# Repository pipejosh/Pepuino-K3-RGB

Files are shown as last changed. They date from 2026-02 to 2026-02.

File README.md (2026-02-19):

# Pepuino K3 RGB 

Introducing the Pepuino K3 RGB, this is a custom macro pad made from scratch, currently designed to fit any rythm game like osu or geometry dash. The Pepuino K3 has 3 programable switches per light RGB lightning and a rotary encoder.

I made this project because I felt like it was time to jump from keyboard to a more small macro pad. I was orignally gonna buy one, but what a better opportunity to learn how to make one myself.

## Mode

In this current set up I have 2 layers, the Osu mode (ESC, z , x) and the Geometry Dash mode (Space , z , x) you can difference them by the led profile, the purple for Osu and the rainbow for Geometry Dash 

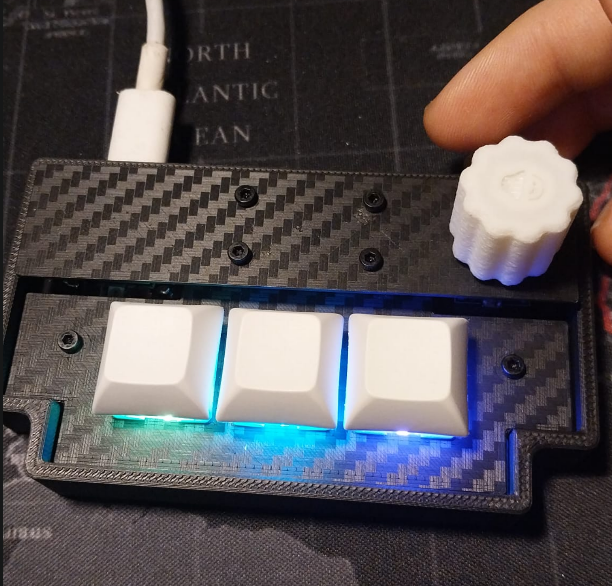
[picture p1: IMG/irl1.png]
geometryDashMode
 
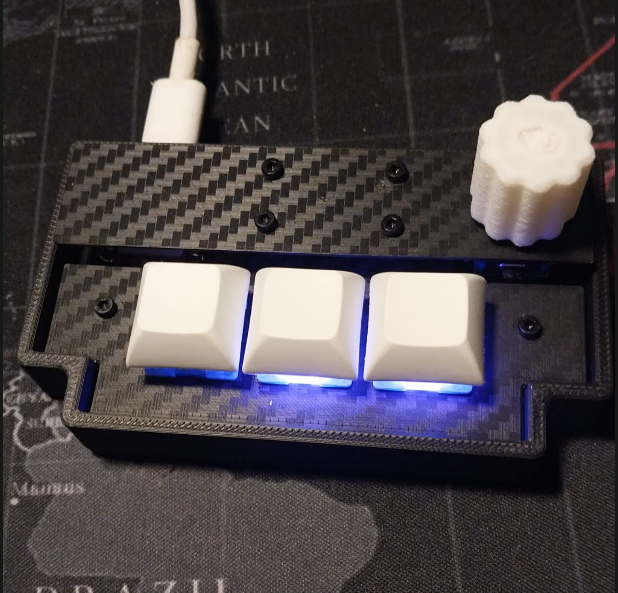
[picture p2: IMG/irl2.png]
osuMode
 

# Technical stuff

### SCHEMATIC DIAGRAM
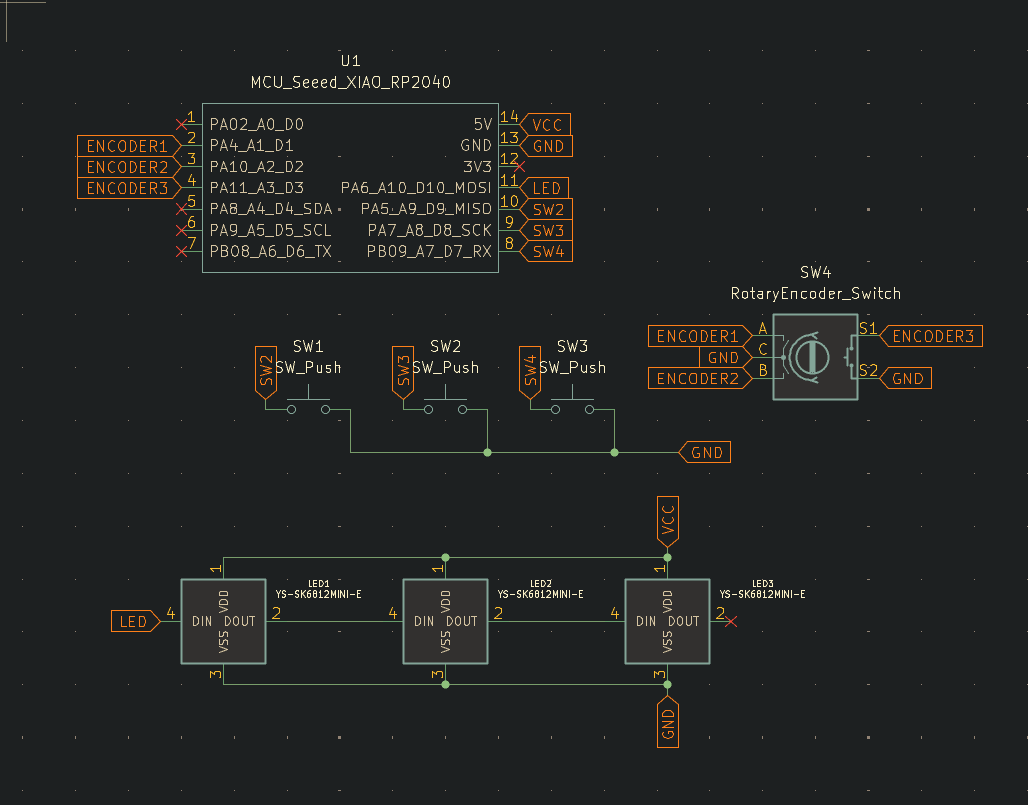
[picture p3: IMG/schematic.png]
shcematic
 

### PCB 
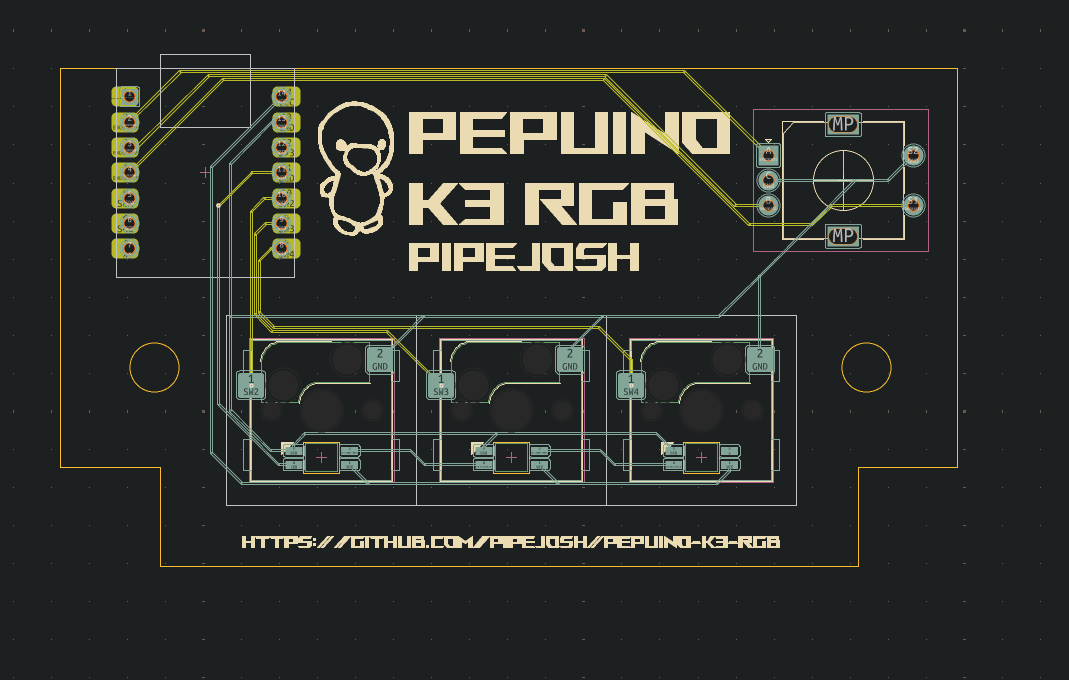
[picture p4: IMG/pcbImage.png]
pcb
 

### CASE RENDER
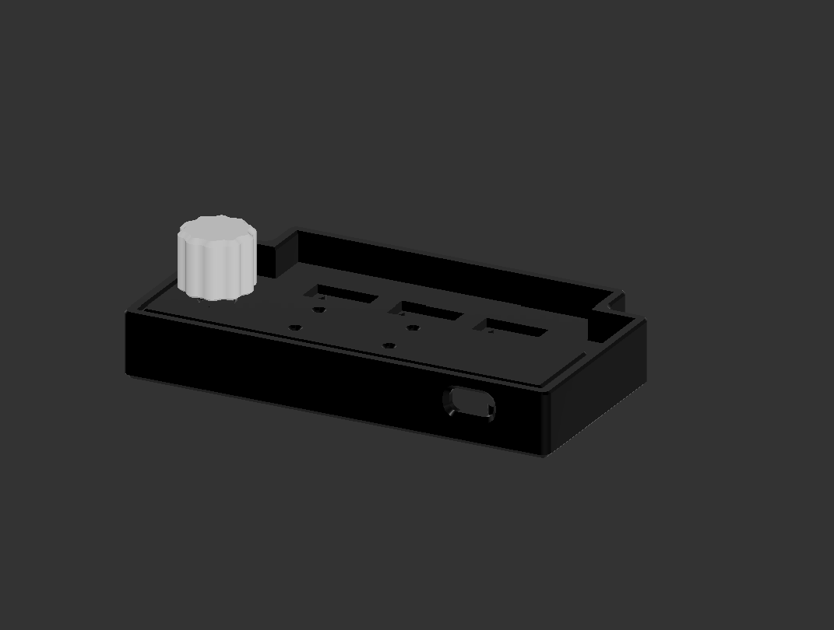
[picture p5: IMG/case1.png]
caseRender1
 
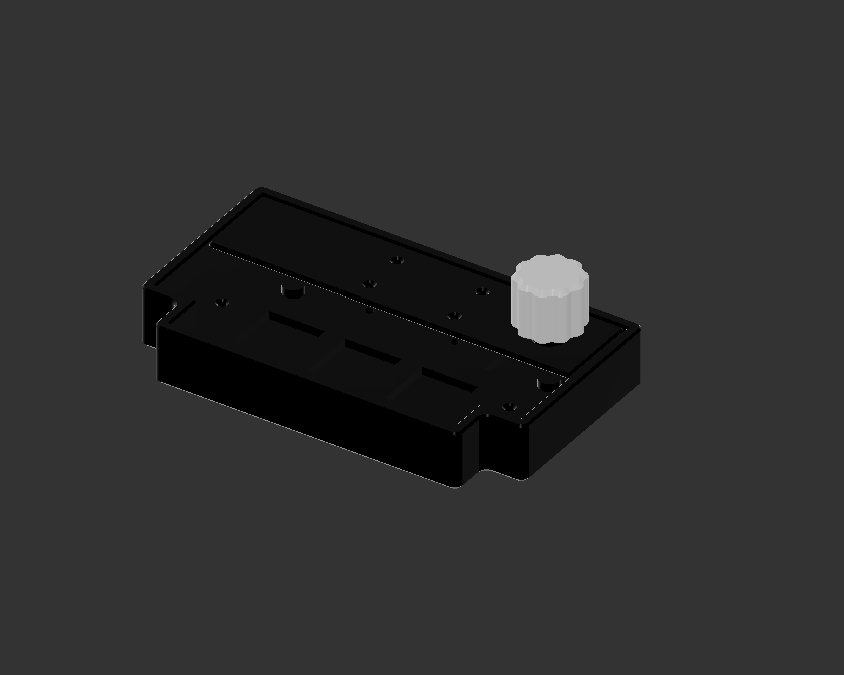
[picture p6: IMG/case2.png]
caseRender2
 

### BOM
####  Components

| Item | Description | Qty | Unit Price | Total Price |
|---|---|-----|---|---|
| xiao rp2040 | — | 1 | 4,54 | 4,54 |
| blank keycaps  | white | 20  | 0,19 | 3,77 |
| switches | mechanical switches| 10  | 0,39 | 3,9 |
| rotary encoder | — | 1 | 1,85 | 1,85 |
| M2 standoff | M2 standoff 5mm | 50  | 0,05 | 2,47 |
| M2 screw | 5mm screw | 50  | 0,03 | 1,65 |

#### Taxes

| Item  | Description | Total Price |
|---|---|---|
| taxes | aliexpress tax | 4,28 |

#### Components Subtotal

| Category | Total |
|---|---|
| Components | 22,46  |

---

#### PCB

| Item | Description | Qty |
|---|---|-----|
| JLCPCB | Pepuino Pad PCB | 1 |
| JLCPCB Shipping | Shipping for PCB + taxes  | 3 |

---

#### Grand Total

| TOTAL |
|-------|
| 26,46 |

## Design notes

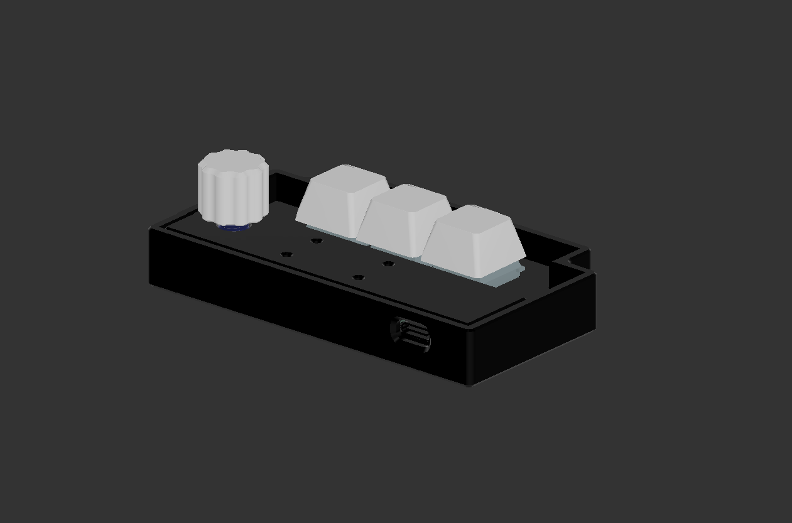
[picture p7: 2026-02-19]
IMG/render1.png

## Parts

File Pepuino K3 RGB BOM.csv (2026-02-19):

KIT Items | Description | Quantity | Unit Price | Total Price | URL
xiao rp2040 |  | 1 | 4,54 | 4,54 | https://www.aliexpress.com/item/1005006987582110.html
blank keycaps | white | 20 | 0,19 | 3,77 | https://www.aliexpress.com/item/1005006116865547.html?spm=a2g0o.detail.0.0.5325TAR5TAR5dv&mp=1
switches | mechanical switches | 10 | 0,39 | 3,9 | https://www.aliexpress.com/item/1005006425450443.html
rotary encoder |  | 1 | 1,85 | 1,85 | https://www.aliexpress.com/item/1005007644083514.html
M2 standoff | M2 standoff 5mm | 50 | 0,05 | 2,47 | https://www.aliexpress.com/item/1005008504707668.html?spm=a2g0o.detail.0.0.5fe4VqYfVqYfAJ&mp=1
M2 screw | 5mm screw | 50 | 0,03 | 1,65 | https://www.aliexpress.com/item/1005005070119421.html
taxes | aliexpress tax |  |  | 4,28
 |  |  | Components | 22,46
CASE Items | Description
JLCPCB | Pepuino Pad PCB | 1
JLCPCB Shipping | Shipping for PCB + taxes | 3
TOTAL | 26,46

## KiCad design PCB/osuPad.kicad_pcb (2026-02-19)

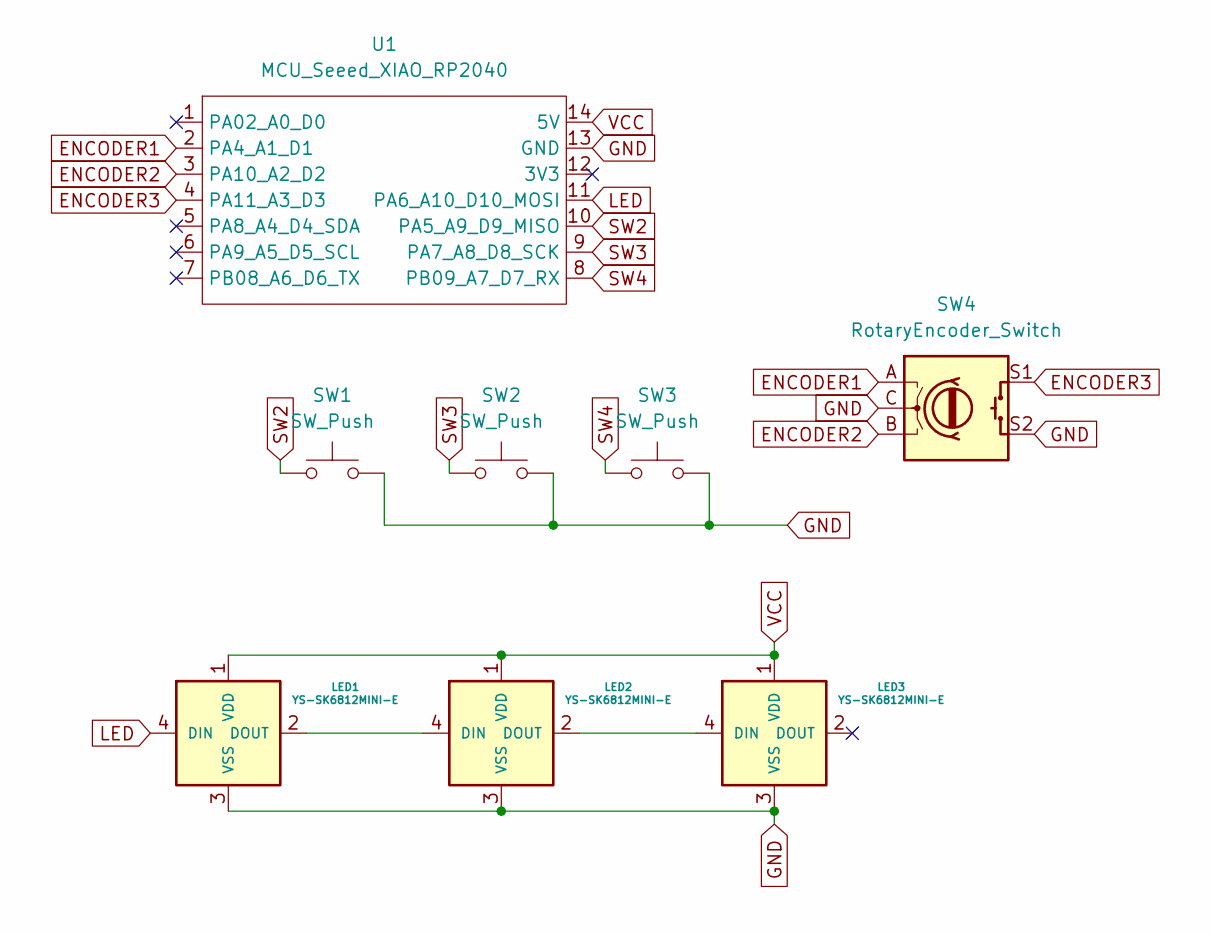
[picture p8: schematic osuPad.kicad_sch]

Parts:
LED1, LED2, LED3: YS-SK6812MINI-E
SW1, SW2, SW3: SW_Push; Hotswap_MX_1.00u
SW4: RotaryEncoder_Switch; RotaryEncoder_Alps_EC11E-Switch_Vertical_H20mm
U1: MCU_Seeed_XIAO_RP2040; Seeed_XIAO_RP2040

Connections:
3V3: U1.12 (3V3)
ENCODER1: SW4.A, U1.2 (PA4_A1_D1)
ENCODER2: SW4.B, U1.3 (PA10_A2_D2)
ENCODER3: SW4.S1, U1.4 (PA11_A3_D3)
GND: LED1.3 (VSS), LED2.3 (VSS), LED3.3 (VSS), SW1.2, SW2.2, SW3.2, SW4.C, SW4.S2, U1.13 (GND)
LED: LED1.4 (DIN), U1.11 (PA6_A10_D10_MOSI)
unnamed: LED1.2 (DOUT), LED2.4 (DIN)
unnamed: LED2.2 (DOUT), LED3.4 (DIN)
SCL: U1.6 (PA9_A5_D5_SCL)
SDA: U1.5 (PA8_A4_D4_SDA)
SW2: SW1.1, U1.10 (PA5_A9_D9_MISO)
SW3: SW2.1, U1.9 (PA7_A8_D8_SCK)
SW4: SW3.1, U1.8 (PB09_A7_D7_RX)
VCC: LED1.1 (VDD), LED2.1 (VDD), LED3.1 (VDD), U1.14 (5V)

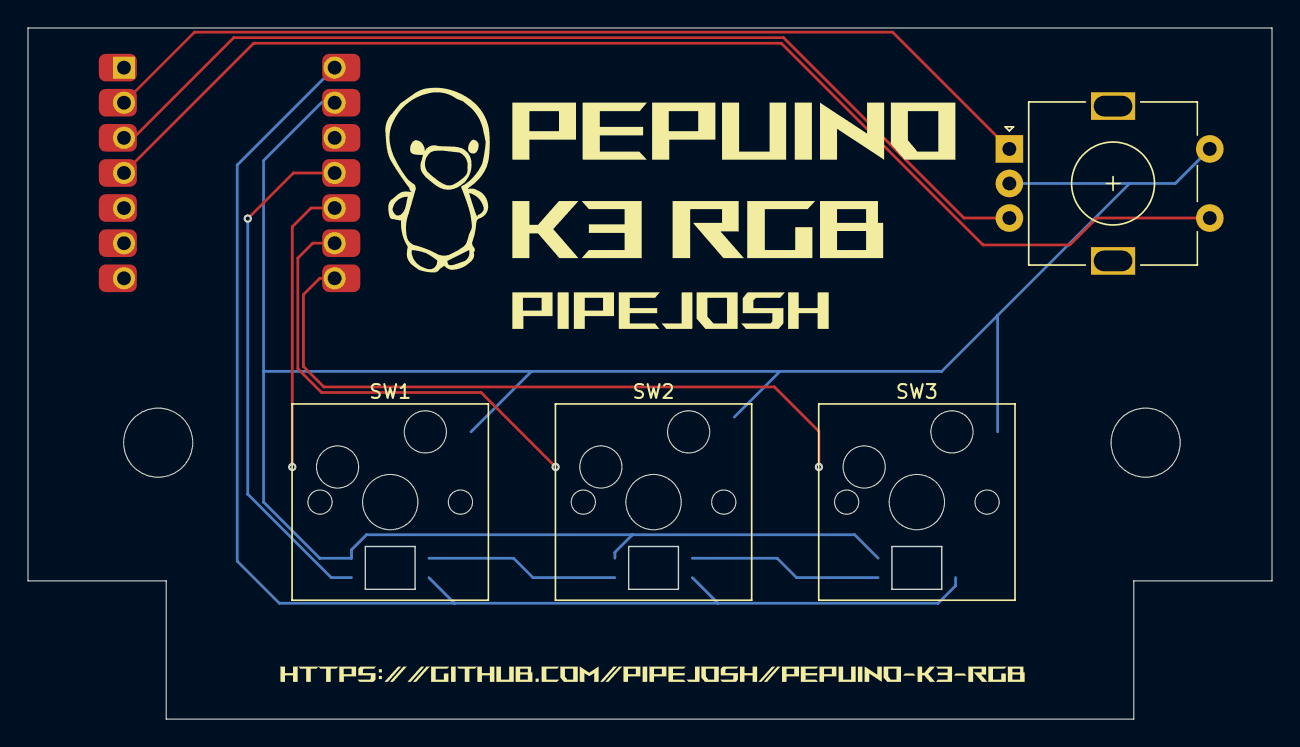
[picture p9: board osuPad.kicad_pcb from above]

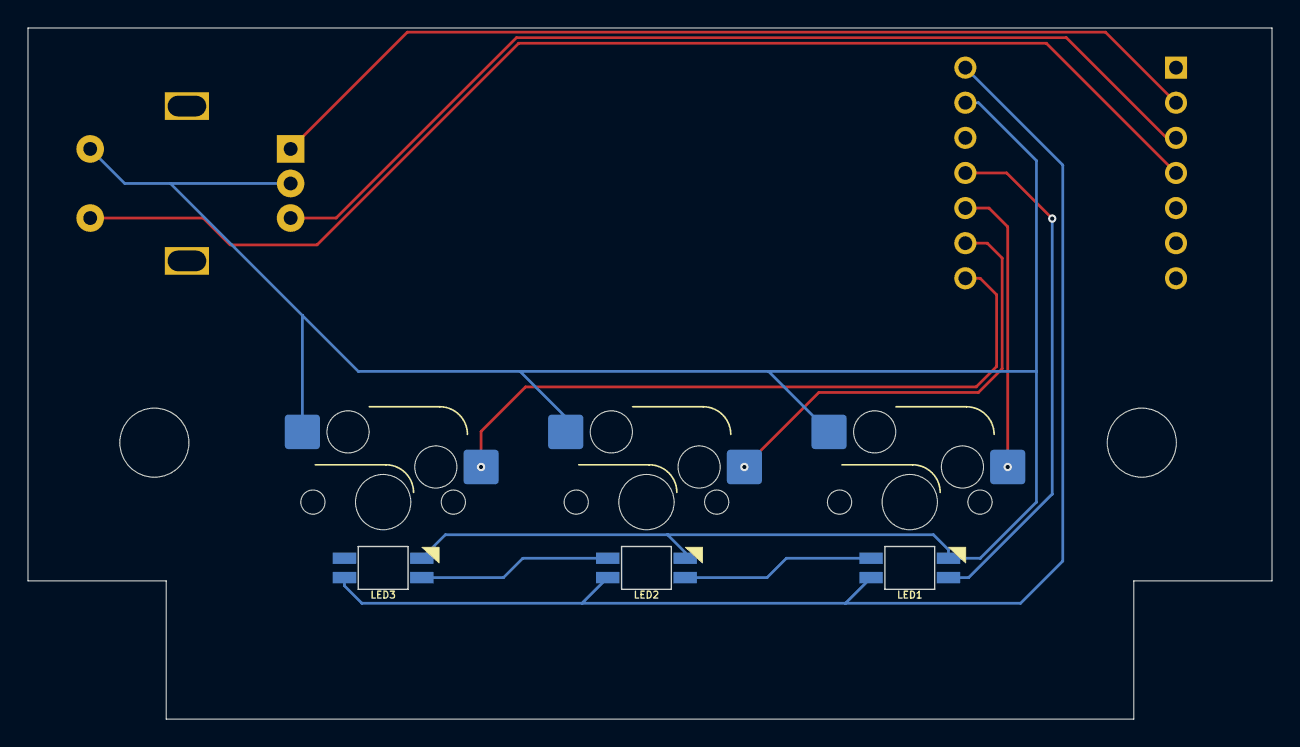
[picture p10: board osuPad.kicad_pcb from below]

Board: 2 copper layers, 90.0 x 50.0 mm, 8 parts (3 on the bottom side), 11 nets.

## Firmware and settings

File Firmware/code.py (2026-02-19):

import board
import time
import usb_hid
import neopixel
import rotaryio

from digitalio import DigitalInOut, Direction, Pull
from adafruit_hid.keyboard import Keyboard
from adafruit_hid.keycode import Keycode
from adafruit_hid.consumer_control import ConsumerControl
from adafruit_hid.consumer_control_code import ConsumerControlCode

# =========================
# CONFIG
# =========================
NUM_LEDS = 3
LONG_PRESS_TIME = 2.0
PRESS_DECAY = 2.5
ROTATION_DECAY = 3.0
SWEEP_SPEED = 1
ROTATION_INTENSITY_SCALE = 1.5
BTN_PRESS_DECAY = 1.0  # per-button white glow decay

# =========================
# HID
# =========================
kbd = Keyboard(usb_hid.devices)
cc = ConsumerControl(usb_hid.devices)

# =========================
# BUTTONS
# =========================
btn_left = DigitalInOut(board.D9)
btn_center = DigitalInOut(board.D0)
btn_right = DigitalInOut(board.D7)

for b in (btn_left, btn_center, btn_right):
    b.direction = Direction.INPUT
    b.pull = Pull.UP

# =========================
# ENCODER
# =========================
encoder = rotaryio.IncrementalEncoder(board.D1, board.D2)
encoder_btn = DigitalInOut(board.D3)
encoder_btn.direction = Direction.INPUT
encoder_btn.pull = Pull.UP

encoder_last_btn = encoder_btn.value
press_start_time = 0
long_press_triggered = False
last_encoder_position = encoder.position

# =========================
# NEOPIXELS
# =========================
pixels = neopixel.NeoPixel(board.D10, NUM_LEDS, brightness=1.0, auto_write=False)

# =========================
# STATE
# =========================
profile = 0  # 0 = OSU, 1 = GD
wave_pos = 0.0
wave_dir = 1
press_energy = 0.0

# Per-button white glow
btn_left_energy = 0.0
btn_center_energy = 0.0
btn_right_energy = 0.0

rotation_energy = 0.0
sweep_pos = 1.0  # fractional position
rotation_direction = 1  # 1 = volume up, -1 = volume down

# =========================
# HELPERS
# =========================
def hsv_to_rgb(h, s, v):
    i = int(h * 6)
    f = h * 6 - i
    p = v * (1 - s)
    q = v * (1 - f * s)
    t = v * (1 - (1 - f) * s)
    i = i % 6
    if i == 0: return (v, t, p)
    if i == 1: return (q, v, p)
    if i == 2: return (p, v, t)
    if i == 3: return (p, q, v)
    if i == 4: return (t, p, v)
    if i == 5: return (v, p, q)

# =========================
# BASE ANIMATIONS
# =========================
def osu_wave(dt):
    global wave_pos, wave_dir
    wave_pos += wave_dir * 2.5 * dt
    if wave_pos > 2: wave_dir = -1
    if wave_pos < 0: wave_dir = 1
    colors = []
    for i in range(NUM_LEDS):
        distance = abs(i - wave_pos)
        brightness = max(0, 1 - distance)
        r = 140 * brightness
        g = 0
        b = 220 * brightness
        colors.append((r, g, b))
    return colors

def gd_wave(dt):
    global wave_pos
    wave_pos += 0.5 * dt
    colors = []
    for i in range(NUM_LEDS):
        hue = (wave_pos + i * 0.25) % 1.0
        r, g, b = hsv_to_rgb(hue, 1, 1)
        colors.append((r*255, g*255, b*255))
    return colors

# =========================
# MAIN LOOP
# =========================
last_time = time.monotonic()

while True:
    now = time.monotonic()
    dt = now - last_time
    last_time = now

    # ---------------------
    # ENCODER ROTATION (INVERTED)
    # ---------------------
    current_pos = encoder.position
    delta = current_pos - last_encoder_position
    if delta != 0:
        rotation_direction = 1 if delta > 0 else -1
        rotation_energy += abs(delta) * ROTATION_INTENSITY_SCALE
        rotation_energy = min(rotation_energy, 3.0)

        # volume control inverted
        if delta > 0:
            cc.send(ConsumerControlCode.VOLUME_DECREMENT)  # CW lowers volume
            sweep_pos -= SWEEP_SPEED * abs(delta)
            if sweep_pos < 0:
                sweep_pos += NUM_LEDS
        else:
            cc.send(ConsumerControlCode.VOLUME_INCREMENT)  # CCW raises volume
            sweep_pos += SWEEP_SPEED * abs(delta)
            if sweep_pos >= NUM_LEDS:
                sweep_pos -= NUM_LEDS

    last_encoder_position = current_pos
    rotation_energy -= ROTATION_DECAY * dt
    if rotation_energy < 0: rotation_energy = 0

    # ---------------------
    # ENCODER BUTTON
    # ---------------------
    current_btn = encoder_btn.value
    if not current_btn and encoder_last_btn:
        press_start_time = now
        long_press_triggered = False
        press_energy = 1.0
    if not current_btn:
        if not long_press_triggered and (now - press_start_time >= LONG_PRESS_TIME):
            profile = 1 - profile
            long_press_triggered = True
            press_energy = 1.5
    if current_btn and not encoder_last_btn:
        if (now - press_start_time) < LONG_PRESS_TIME:
            cc.send(ConsumerControlCode.PLAY_PAUSE)
    encoder_last_btn = current_btn

    press_energy -= PRESS_DECAY * dt
    if press_energy < 0: press_energy = 0

    # ---------------------
    # BUTTON MAPPING + PER-BUTTON WHITE GLOW
    # ---------------------
    if profile == 0:  # OSU
        if not btn_left.value:
            kbd.press(Keycode.ESCAPE)
            btn_left_energy = 1.0
        else:
            kbd.release(Keycode.ESCAPE)
        if not btn_center.value:
            kbd.press(Keycode.Z)
            btn_center_energy = 1.0
        else:
            kbd.release(Keycode.Z)
        if not btn_right.value:
            kbd.press(Keycode.X)
            btn_right_energy = 1.0
        else:
            kbd.release(Keycode.X)
    else:  # GD
        if not btn_left.value:
            kbd.press(Keycode.SPACE)
            btn_left_energy = 1.0
        else:
            kbd.release(Keycode.SPACE)
        if not btn_center.value:
            kbd.press(Keycode.UP_ARROW)
            btn_center_energy = 1.0
        else:
            kbd.release(Keycode.UP_ARROW)
        if not btn_right.value:
            kbd.press(Keycode.DOWN_ARROW)
            btn_right_energy = 1.0
        else:
            kbd.release(Keycode.DOWN_ARROW)

    # decay per-button energies
    btn_left_energy -= BTN_PRESS_DECAY * dt
    btn_center_energy -= BTN_PRESS_DECAY * dt
    btn_right_energy -= BTN_PRESS_DECAY * dt
    btn_left_energy = max(0, btn_left_energy)
    btn_center_energy = max(0, btn_center_energy)
    btn_right_energy = max(0, btn_right_energy)

    # ---------------------
    # BASE COLORS + OVERLAYS
    # ---------------------
    base = osu_wave(dt) if profile == 0 else gd_wave(dt)
    final = []

    for i in range(NUM_LEDS):
        r, g, b = base[i]

        # rotation sweep overlay
        if rotation_energy > 0:
            dist = abs(i - sweep_pos)
            dist = min(dist, NUM_LEDS - dist)
            sweep_brightness = max(0, 1 - dist) * rotation_energy
            r += 255 * sweep_brightness
            g += 255 * sweep_brightness
            b += 255 * sweep_brightness

        # encoder press overlay
        if press_energy > 0:
            r += 255 * press_energy
            g += 255 * press_energy
            b += 255 * press_energy

        # per-button white glow
        if i == 0:
            r += 100 * btn_left_energy
            g += 100 * btn_left_energy
            b += 100 * btn_left_energy
        elif i == 1:
            r += 100 * btn_center_energy
            g += 100 * btn_center_energy
            b += 100 * btn_center_energy
        elif i == 2:
            r += 100 * btn_right_energy
            g += 100 * btn_right_energy
            b += 100 * btn_right_energy

        final.append((min(255,int(r)), min(255,int(g)), min(255,int(b))))

    # update LEDs
    for i in range(NUM_LEDS):
        pixels[i] = final[i]
    pixels.show()

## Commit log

2025-11-30 Created the case
    The case is doneeEeEEeEeeeee!!!
2025-11-30 create document structure
    [osuPad.kicad_pcb, osuPad.kicad_sch, osuPad.step]
2025-11-30 add schematic
    [osuPad.kicad_sch]
2025-11-30 update BOM
2026-02-19 update pcb, case, and readme
    [designators.csv, freerouting.dsn, osuPad.kicad_pcb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]
2026-02-19 Rename PCB image reference in README
2026-02-19 Fix PCB image filename in README
    Updated PCB image reference in README.md.
2026-02-19 add bom
    [Pepuino K3 RGB BOM.csv]
2026-02-19 Add BOM section with components and pricing details
    Added Bill of Materials (BOM) section with components, taxes, and totals.
2026-02-19 Update PCB image in README
